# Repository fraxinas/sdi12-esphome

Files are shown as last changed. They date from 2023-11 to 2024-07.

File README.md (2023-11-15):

# SDI-12 Interface for ESPHome

(CC) 2023 by Andreas Frisch <github@fraxinas.dev>

## OwO what's this?
**`sdi12-esphome` is an ESP32-based interface for connecting professional meteorologic sensors with ESPHome and Home Assistant**
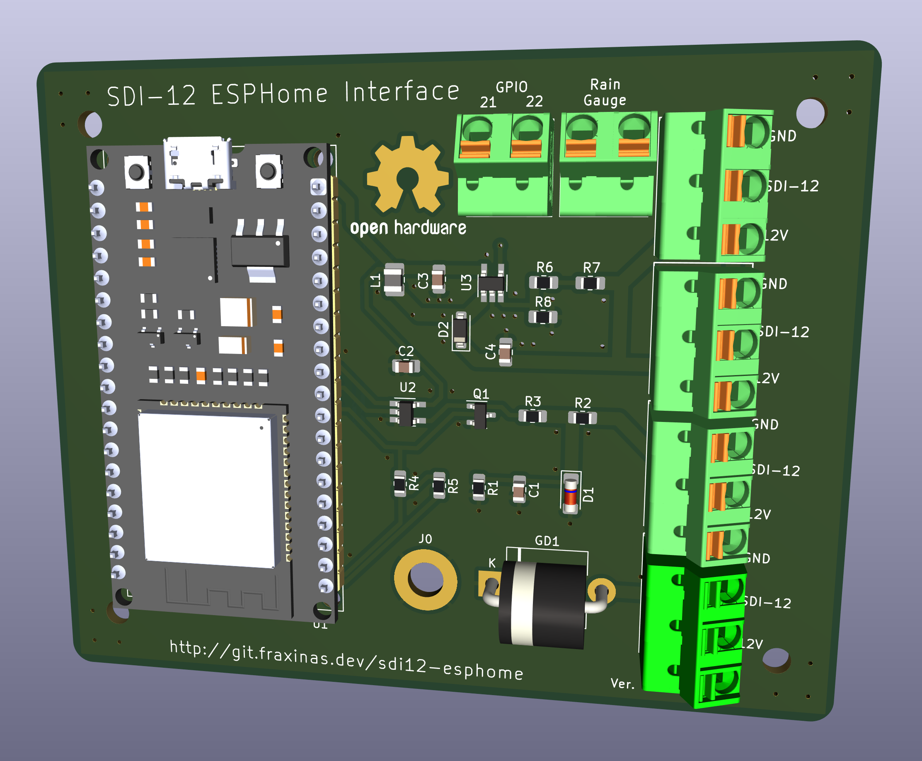
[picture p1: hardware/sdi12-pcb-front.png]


## Hardware Features
* Based on a NodeMCU ESP32 Module
* 4x SDI-12 inputs via push-in terminals
* Step-up conversion for the 12V SDI-12 sensor power
* Transient surge protection for the SDI-12 data bus
* PCB fits into a BOPLA 100x100mm IP65 case

## Software Features
* Home Assistant intergration using ESPHome.io

## Custom Components
### SDI-12 Bus
* is a wrapper around the https://github.com/EnviroDIY/Arduino-SDI-12 library, with the https://github.com/RAKWireless/RAK13010-SDI12/ modifications to split input, output and enable into separate GPIOs
* allows configuring an SDI-12 Bus component that sensors can be attached to
* configure RX, TX & OE pins through configuration YAML
* provide address scan method

### CS215
* Campbell Scientific CS215 Temperature and Relative Humidity Probe
* https://s.campbellsci.com/documents/ca/manuals/cs215_man.pdf

### DS2
* Decagon Devices DS-2 Sonic Anemometer
* https://library.metergroup.com/Manuals/14586_DS2_Web.pdf
* Sensors for
  * wind speed
  * wind direction
  * wind temperature

### TODOs
- [ ] SDI-12 Bus component (feature complete & tests)
- [ ] Themometer/Hygrometer (feature complete & tests)
- [ ] Anemometer (feature complete & tests)
- [ ] Rain Gauge (start)
- [ ] Generic Sensor (start)
- [ ] Documentation / Photos

## Project Diary
| Date | Version | Milestone |
| :--- | :--- | :--- |
| 2023-10-22 | | Started Project on the breadboard |
| 2023-11-06 | | First successful sensor readout in EPSHome |
| 2023-11-13 |  v0.1 | Order prototype design at JLCPCB |

## Resources
* https://www.sdi-12.org/current_specification/SDI-12_version-1_4-Jan-10-2019.pdf
* https://ww1.microchip.com/downloads/en/DeviceDoc/20005315B.pdf

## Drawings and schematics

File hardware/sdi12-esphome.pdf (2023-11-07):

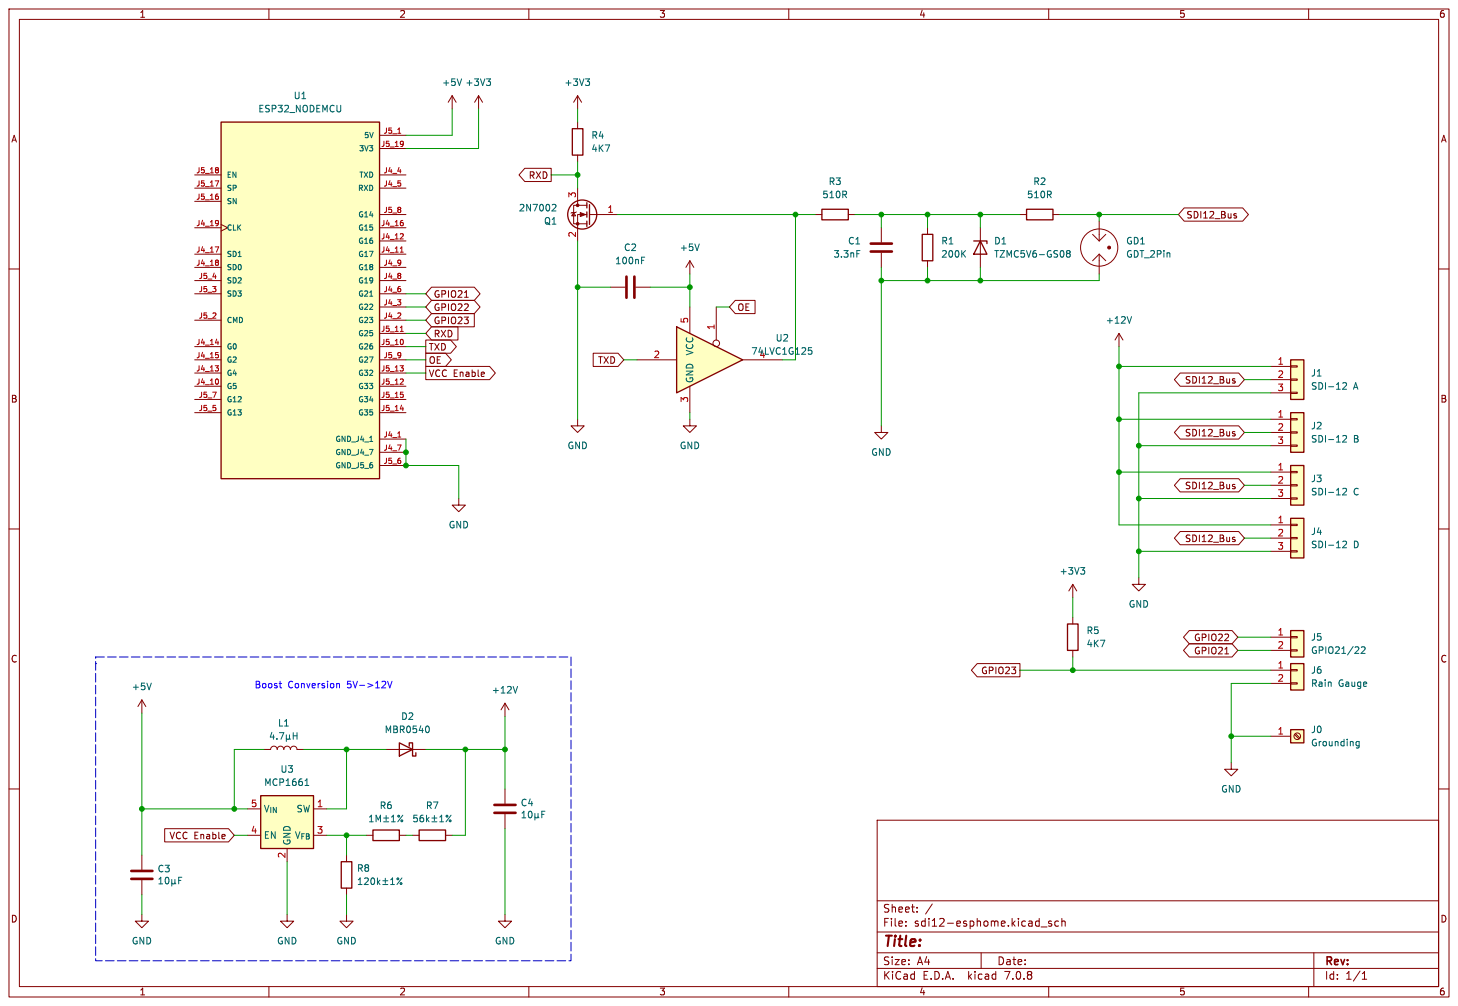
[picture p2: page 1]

2 V_{FB}3 EN 4 V_{IN} 5 U3 MCP1661 GND

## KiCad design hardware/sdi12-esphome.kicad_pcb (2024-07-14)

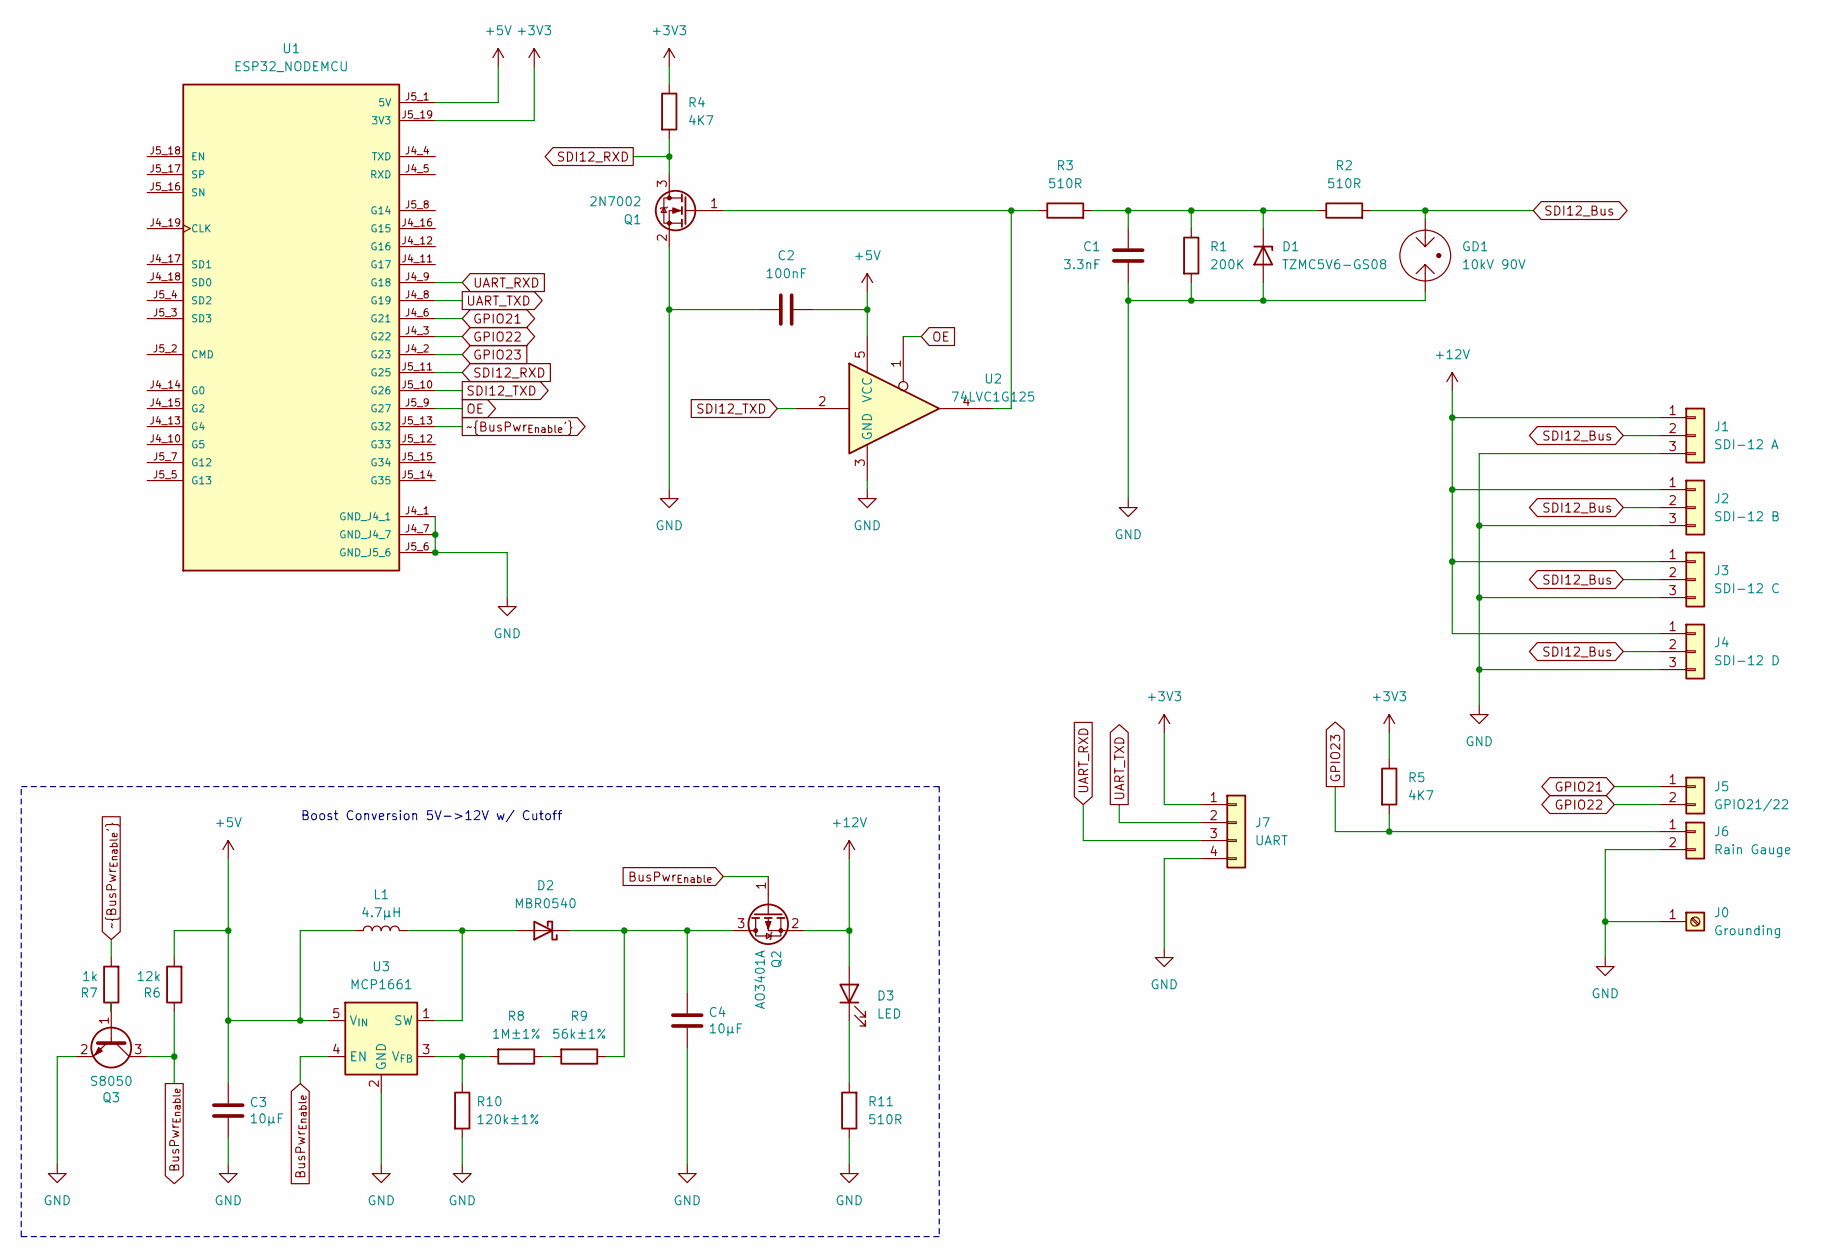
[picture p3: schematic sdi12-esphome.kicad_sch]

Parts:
C1: 3.3nF; C_0805_2012Metric_Pad1.18x1.45mm_HandSolder
C2: 100nF; C_0805_2012Metric_Pad1.18x1.45mm_HandSolder
C3, C4: 10µF; C_0805_2012Metric_Pad1.18x1.45mm_HandSolder
D1: TZMC5V6-GS08; D_MiniMELF
D2: MBR0540; D_SOD-123
D3: LED; LED_0805_2012Metric_Pad1.15x1.40mm_HandSolder
GD1: 10kV 90V; Gas Discharge Tube Generic 12.7mm THT
J0: Grounding; MountingHole_4.3mm_M4_ISO7380_Pad_TopBottom
J1: SDI-12 A; Phoenix Contact SPTA 1 3 5,0 1752227
J2: SDI-12 B; Phoenix Contact SPTA 1 3 5,0 1752227
J3: SDI-12 C; Phoenix Contact SPTA 1 3 5,0 1752227
J4: SDI-12 D; Phoenix Contact SPTA 1 3 5,0 1752227
J5: GPIO21/22; Phoenix Contact SPTA 1 2 5,0 1752214
J6: Rain Gauge; Phoenix Contact SPTA 1 2 5,0 1752214
J7: UART; PinSocket_1x04_P2.54mm_Vertical
L1: 4.7µH; L_1008_2520Metric_Pad1.43x2.20mm_HandSolder
Q1: 2N7002; SOT-23
Q2: AO3401A; SOT-23
Q3: S8050; SOT-23
R1: 200K; R_0805_2012Metric_Pad1.20x1.40mm_HandSolder
R2, R3, R11: 510R; R_0805_2012Metric_Pad1.20x1.40mm_HandSolder
R4, R5: 4K7; R_0805_2012Metric_Pad1.20x1.40mm_HandSolder
R6: 12k; R_0805_2012Metric_Pad1.20x1.40mm_HandSolder
R7: 1k; R_0805_2012Metric_Pad1.20x1.40mm_HandSolder
R8: 1M±1%; R_0805_2012Metric_Pad1.20x1.40mm_HandSolder
R9: 56k±1%; R_0805_2012Metric_Pad1.20x1.40mm_HandSolder
R10: 120k±1%; R_0805_2012Metric_Pad1.20x1.40mm_HandSolder
U1: ESP32_NODEMCU; MODULE_ESP32_NODEMCU
U2: 74LVC1G125; SOT-23-5_HandSoldering
U3: MCP1661; SOT-23-5_HandSoldering

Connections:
+3V3: J7.1, R4.1, R5.1, U1.J5_19 (3V3)
+5V: C2.2, C3.1, L1.1, R6.2, U1.J5_1 (5V), U2.5 (VCC), U3.5 (V_{IN})
+12V: D3.2 (A), J1.1, J2.1, J3.1, J4.1, Q2.2 (S)
BusPwr_{Enable}: Q2.1 (G), Q3.3 (C), R6.1, U3.4 (EN)
GND: C1.2, C2.1, C3.2, C4.2, D1.2 (A), GD1.1, J0.1, J1.3, J2.3, J3.3, J4.3, J6.2, J7.4, Q1.2 (S), Q3.2 (E), R1.2, R10.2, R11.1, U1.J4_1 (GND_J4_1), U1.J4_7 (GND_J4_7), U1.J5_6 (GND_J5_6), U2.3 (GND), U3.2 (GND)
GPIO21: J5.1, U1.J4_6 (G21)
GPIO22: J5.2, U1.J4_3 (G22)
GPIO23: J6.1, R5.2, U1.J4_2 (G23)
unnamed: C1.1, D1.1 (K), R1.1, R2.1, R3.2
unnamed: D2.2 (A), L1.2, U3.1 (SW)
unnamed: C4.1, D2.1 (K), Q2.3 (D), R9.1
unnamed: D3.1 (K), R11.2
unnamed: Q1.1 (G), R3.1, U2.4
unnamed: Q3.1 (B), R7.1
unnamed: R8.1, R9.2
unnamed: R8.2, R10.1, U3.3 (V_{FB})
OE: U1.J5_9 (G27), U2.1
SDI12_Bus: GD1.3, J1.2, J2.2, J3.2, J4.2, R2.2
SDI12_RXD: Q1.3 (D), R4.2, U1.J5_11 (G25)
SDI12_TXD: U1.J5_10 (G26), U2.2
UART_RXD: J7.3, U1.J4_9 (G18)
UART_TXD: J7.2, U1.J4_8 (G19)
~BusPwr_{Enable'}: R7.2, U1.J5_13 (G32)

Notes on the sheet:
Boost Conversion 5V->12V w/ Cutoff

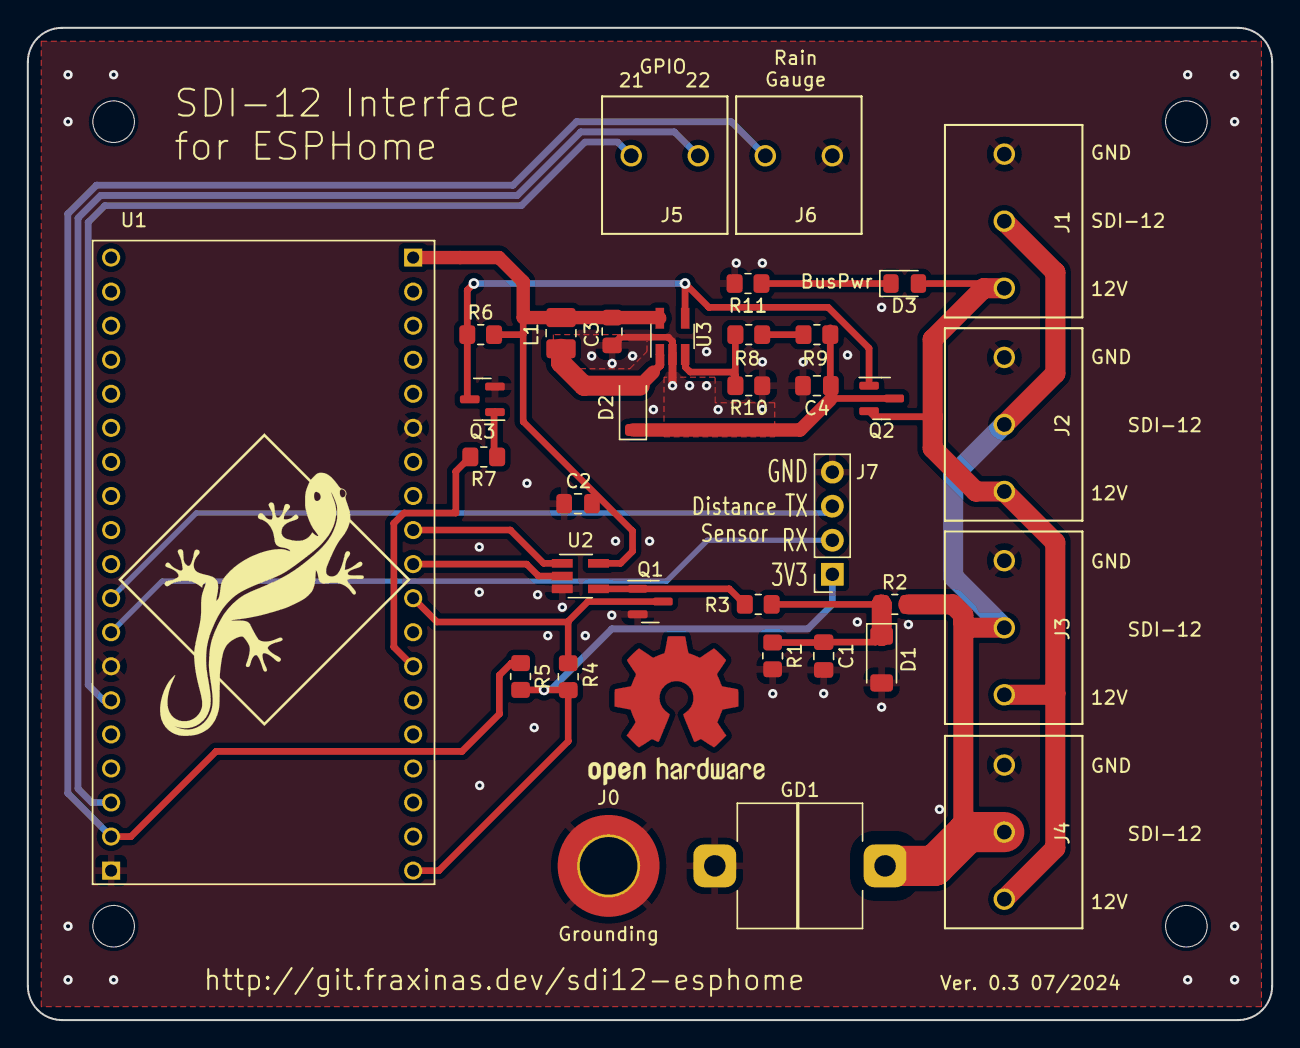
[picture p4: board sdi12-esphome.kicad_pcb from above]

Board: 2 copper layers, 92.8 x 74.0 mm, 35 parts (0 on the bottom side), 23 nets.

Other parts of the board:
LOGO1: Logo_Open_Hardware_Small; OSHW-Logo2_14.6x12mm_Mask

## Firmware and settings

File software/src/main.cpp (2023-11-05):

/**
   @file RAK13010_SDI_12_Check_All_Addresses.ino
   @author rakwireless.com
   @brief  Check all Addresses for Active Sensors and Print Status.
           It discovers the address of all sensors active and attached to the board.
           THIS CAN BE *REALLY* SLOW TO RUN!!!
           Each sensor should have a unique address already - if not, multiple sensors may
           respond simultaenously to the same request and the output will not be readable
           by the Arduino.
   @version 0.1
   @date 2022-03-11
   @copyright Copyright (c) 2022
**/
#include "RAK13010_SDI12.h" // Click to install library: // Click to install library: http://librarymanager/All#RAK13010

#define RX_PIN 25 // The pin of the SDI-12 data bus.
#define TX_PIN 26 // The pin of the SDI-12 data bus.

#define OE 27    // Output enable pin, active low.

RAK_SDI12 mySDI12(RX_PIN, TX_PIN, OE);

/**
 * @brief Gets identification information from a sensor, and prints it to the serial port expects.
 * @param i A character between '0'-'9', 'a'-'z', or 'A'-'Z'
 */
void printInfo(char i)
{
  String command = "";
  command += (char)i;
  command += "I!";
  mySDI12.sendCommand(command);
  mySDI12.clearBuffer();
  delay(30);

  Serial.print("  --");
  Serial.print(i);
  Serial.print("--  ");

  while (mySDI12.available())
  {
    Serial.write(mySDI12.read());
    delay(10); // 1 character ~ 7.5ms.
  }
  Serial.print("\r\n");
}

/**
 * @brief this checks for activity at a particular address.
 * @param i A character between '0'-'9', 'a'-'z', or 'A'-'Z'
 */
boolean checkActive(char i)
{
  String myCommand = "";
  myCommand += (char)i; // Sends basic 'acknowledge' command [address][!].
  myCommand += "!";

  for (int j = 0; j < 3; j++)
  {
    mySDI12.sendCommand(myCommand, 20);
    mySDI12.clearBuffer();
    delay(20);
    if (mySDI12.available())
    {
      return true;
    }
  }
  mySDI12.clearBuffer();
  return false;
}

void scanAddressSpace(void)
{
  // while (1)
  {
    for (char i = '0'; i <= '9'; i++) // Scan address space 0-9.
    {
      Serial.printf("Scan Address Space = %c\r\n", i);
      if (checkActive(i))
      {
        printInfo(i);
      }
    }

    for (char i = 'a'; i <= 'z'; i++) // Scan address space a-z.
    {
      Serial.printf("Scan Address Space = %c\r\n", i);
      if (checkActive(i))
      {
        printInfo(i);
      }
    }

    for (char i = 'A'; i <= 'Z'; i++) // Scan address space A-Z.
    {
      Serial.printf("Scan Address Space = %c\r\n", i);
      if (checkActive(i))
      {
        printInfo(i);
      }
    }
  }
}

void addressQueryFindDelay()
{
  String command = "?!";

  Serial.print("  address query find delay: ");

  for (int d = 0; d < 150; d += 2)
  {
    mySDI12.sendCommand(command, d);
    mySDI12.clearBuffer();
    // delay(d);
    mySDI12.sendCommand(command);
    mySDI12.clearBuffer();
    delay(d);
    if (mySDI12.available())
    {
      Serial.printf("available after %dms: ", d);
      {
        Serial.write(mySDI12.read());
        delay(10); // 1 character ~ 7.5ms.
      }
      Serial.printf("\r\n");
      return;
    } else {
      Serial.printf("%d ", d);
    }
  }
  Serial.write("unavailable!\r\n");
}

void addressQueryFindDelay2()
{
  String command = "?!";

  for (int d = 5; d<105; d+=5)
  {
    Serial.printf("Address query with %d ms delay: ", d);

    // for (int j = 0; j < 3; j++)
    {
      mySDI12.sendCommand(command, d);
      mySDI12.clearBuffer();
      mySDI12.sendCommand(command);
      mySDI12.clearBuffer();
      delay(d);
      // Serial.printf("#%d ",j);
      while (mySDI12.available())
      {
        Serial.write(mySDI12.read());
        delay(10); // 1 character ~ 7.5ms.
      }
    }
    mySDI12.clearBuffer();
    Serial.write("\r\n");
  }
}

void addressQuery(int d)
{
  String command = "?!";

  mySDI12.sendCommand(command, d);
  mySDI12.clearBuffer();

  mySDI12.sendCommand(command);
  mySDI12.clearBuffer();

  mySDI12.sendCommand(command);
  mySDI12.clearBuffer();

  delay(d);

  Serial.print("  address query: ");

  if (mySDI12.available())
  {
    Serial.printf("available after %dms: ", d);
    {
      Serial.write(mySDI12.read());
      delay(10); // 1 character ~ 7.5ms.
    }
    Serial.printf("\r\n");
    return;
  }
  Serial.printf("No reply to address query with delay=%dms\r\n", d);
}

void requestMeasurement(char i)
{
  String command = "";
  command += (char)i;
  command += "M!";
  mySDI12.sendCommand(command,100);
  mySDI12.clearBuffer();

  delay(30);

  Serial.printf("  requestMeasurement with command '%s': ", command.c_str());

  while (mySDI12.available())
  {
    Serial.write(mySDI12.read());
    delay(10); // 1 character ~ 7.5ms.
  }
}

void sendData(char i)
{
  String command = "";
  command += (char)i;
  command += "D0!";
  mySDI12.sendCommand(command,100);
  mySDI12.clearBuffer();
  delay(30);

  Serial.print("  sendData --");
  Serial.print(i);
  Serial.print("--  ");

  while (mySDI12.available())
  {
    Serial.write(mySDI12.read());
    delay(10); // 1 character ~ 7.5ms.
  }
}

void toggleRecorder()
{
  String command = "";
  command += "R!";
  mySDI12.sendCommand(command);
  mySDI12.clearBuffer();
  delay(30);

  Serial.print("  toggleRecorder --");
  Serial.print("--  ");

  while (1) {
    while (mySDI12.available())
    {
      Serial.write(mySDI12.read());
      delay(10); // 1 character ~ 7.5ms.
    }
    delay(500);
  }
}


void setup()
{
  // pinMode(WB_IO2, OUTPUT);
  // digitalWrite(WB_IO2, HIGH); // Power the sensors.

  // Initialize Serial for debug output.
  time_t timeout = millis();
  Serial.begin(115200);
  while (!Serial)
  {
    if ((millis() - timeout) < 5000)
    {
      delay(100);
    }
    else
    {
      break;
    }
  }
  Serial.println("Start Search for SDI-12 Devices.");

  mySDI12.begin();
  delay(4000);
  // addressQuery(20);
  // delay(4000);
  requestMeasurement('0');
  delay(2000);
  sendData('0');
  delay(2000);
  addressQueryFindDelay();
  delay(2500);
  addressQueryFindDelay2();

  // addressQuery();
  delay(2500);
  scanAddressSpace();
  // delay(2500);
  // printInfo('0');
  // delay(2500);
  // requestMeasurement('0');
  // delay(2500);
  // sendData('0');
  // delay(2500);
  // toggleRecorder();

  mySDI12.end();

  Serial.println("End Search for SDI-12 Devices.");

  // digitalWrite(WB_IO2, LOW); // Cut power.
}

void loop()
{
  delay(100);
}

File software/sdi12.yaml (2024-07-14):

esphome:
  name: sdi12-weather
  platform: ESP32
  board: nodemcu-32s

external_components:
  - source:
      type: local
      path: custom_components

wifi:
  ssid: !secret wifi_ssid
  password: !secret wifi_password

  # Enable fallback hotspot (captive portal) in case wifi connection fails
  ap:
    ssid: "SDI-12 Fallback Hotspot"
    password: !secret fallback_password

# Enable logging
logger:
  level: VERBOSE

# Enable Home Assistant API
api:

ota:

sdi12:
  rx_pin: 25
  tx_pin: 26
  enable_pin: 27
  scan: False
  id: bus_a

uart:
  tx_pin: 21
  rx_pin: 22
  baud_rate: 9600

sensor:
  - platform: cs215
    address: 0
    temperature:
      name: "Temperature"
      id: outside_temperature
      filters:
        - median:
            window_size: 12
            send_every: 5
    humidity:
      name: "Humidity"
      id: outside_humidity
      filters:
        - delta: 2.0
  # - platform: ds2
  #   address: 5
  #   wind_speed:
  #     name: "Windspeed"
  #     id: ds2_windspeed
  #   wind_direction_degrees:
  #     name: "Winddirection"
  #     id: ds2_winddirection
  #   temperature:
  #     name: "Windtemperature"
  #     id: ds_windtemperature
  - platform: "jsn_sr04t"
    name: "Obere Zisterne"
    model: "rcwl_1655"
    update_interval: 2s
    filters:
      - lambda: |-
          const float min_distance = 0.3;
          const float max_distance = 1.5;
          float fill_level = (max_distance - x) / (max_distance - min_distance) * 100.0;
          return fill_level;
    unit_of_measurement: "%"
    accuracy_decimals: 0

# switch:
#   - platform: gpio
#     pin:
#       number: 32
#       inverted: true
#     id: sensor_power
#     name: "Sensor Power"

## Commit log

2023-10-29 schematic: Fix GND Net name, import project settings (trace widths etc.)
    [sdi12-esphome.kicad_sch]
2023-10-30 initial commit: Add KiCAD project with basic schematic
    [sdi12-esphome.kicad_sch]
2023-10-30 Schematic: Add 12V boost converter for sensor power
    [sdi12-esphome.kicad_sch]
2023-10-30 schematic: Add BUS terminals, fixup global labels
    [sdi12-esphome.kicad_sch]
2023-10-30 board: Add initial version of PCB layout
    [sdi12-esphome.kicad_pcb]
2023-10-30 board: Resize Board to fit Case, add Silkscreen Descriptions & Artwork
    * Fits into BOPLA EM 212 (62212000) 100x100 mm Case
    [sdi12-esphome.kicad_pcb]
2023-11-01 hardware: Move KiCAD files into hardware subdir
    [sdi12-esphome.kicad_pcb, sdi12-esphome.kicad_sch]
2023-11-02 ds2: Add DS2 Sensor component dummy
2023-11-02 Software: Add DS2 test sensor to configuration
2023-11-03 ds2: Add wind direction and temperature sensors & implement update function
2023-11-04 sdi12: Add missing implementation for Timer Prescaler functions
    * These are NOP for anything non-AVR anyways
2023-11-04 sdi12: Work on test application
    * Make Pin setup consistent with ESPHome component
    * Add function which finds the necessary individual delay for a SDI-12 device
2023-11-05 sdi1: Work on test application, tweak timing
    With the CS215 sensor, timing is absolutely crucial
    Found the only working sequence of requesting address from it
2023-11-05 cs215: Add skeleton SDI-12 Humidity & Temperature Probe CS 215
2023-11-05 cs215: Add timed data request function
    * this properly receives the sensor data (temperature and humidity)
    * parsing TBD
2023-11-06 SDI12: Perform sinlge bus address scans in loop function
    * This avoids tripping the watchdog timer
2023-11-07 hardware: Rename and fix footprints and 3D assets for Terminals
2023-11-07 Schematic: Add additional GPIO and Rain Gauge ports, re-arrange schematic elements
    [sdi12-esphome.kicad_sch]
2023-11-07 board: Add additional GPIO and Rain Gauge ports, re-arrange PCB elements
    [sdi12-esphome.kicad_pcb]
2023-11-07 hardware: Add 3D model for 2x Terminal
    [sdi12-esphome.kicad_pcb]
2023-11-07 software: Add DS2 Windtemperature and Winddirection sensors to config
2023-11-07 hardware: Add Schematic PDF
2023-11-07 Hardware: Add PCB 3D rendering
2023-11-08 Readme: Add Custom components' descriptions & PCB rendering
2023-11-09 hardware: Fix Terminals' footprints
    Move Silkscreen prints away from pads (DRC rule)
2023-11-09 hardware: Add dedicated footprint for Gas Discharge Tube
    * using the diode one was confusing the DRC
2023-11-09 schematic: Add Bus Power indicator LED, use GD footprint, fix terminal mod
    [sdi12-esphome.kicad_sch]
2023-11-09 board: Implement LED, re-arrange snubber and boost converter
    * also fix some DRC problems
    [sdi12-esphome.kicad_pcb]
2023-11-13 board: Import Aisler's simple board properties
    [sdi12-esphome.kicad_pcb]
2023-11-13 board: Update all Vias to spec
    [sdi12-esphome.kicad_pcb]
2023-11-13 library: Remove DRC conflicting solder_mask_margin from NodeMCU footprint
2023-11-13 board: Fix DRC errors (trace min spacing undercuts)
    [sdi12-esphome.kicad_pcb]
2023-11-14 gerber: Export manufacturing data
    [sdi12-esphome-B_Cu.gbr, sdi12-esphome-B_Mask.gbr, sdi12-esphome-B_Paste.gbr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]
2023-11-24 Schematic: Add P-MOSFET for power cutoff
    [sdi12-esphome.kicad_sch]
2023-11-25 Board: Layout for power cut-off MOSFET
    [sdi12-esphome.kicad_pcb]
2023-11-26 Schematic: Add additional NPN for level shifting the BusPwrEnable signal
    [sdi12-esphome.kicad_sch]
2024-07-14 Add Header for RCWL-1655 Distance Sensor Module
    [sdi12-esphome.kicad_pcb, sdi12-esphome.kicad_sch]
2024-07-14 Add custom component for reading out RCWL-1655 Distance sensors for cistern filling level
